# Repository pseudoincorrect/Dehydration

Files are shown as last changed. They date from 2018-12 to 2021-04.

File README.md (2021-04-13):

<h1 align="center">Dehydration Measurement System</h1>



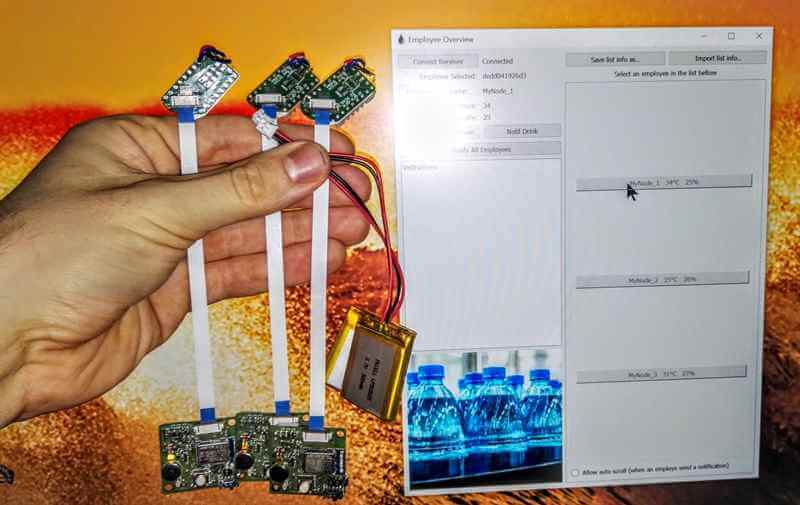
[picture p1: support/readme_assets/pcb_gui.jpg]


# Quick Description

PCB, Embedded system firmware and complementary GUI to measure the vital signs of a group of individuals.
<br>
This project's code "Dehydration" is due to the final objective to analyze data and display a dehydration level of the user. 
<br>
(Machine Learning involved, from the data science department) 
<br>

# Details

This system enable us to measure different various physical values of a group of subjects and record/display them on desktop application. The values measured are skin temperature, surrounding humidity and surrounding temperature.
<br>

## Embedded System and PCB
The embedded system communicates with bluetooth LE to a base station connected to a computer. 
<br>
It uses the Nordic NRF SDK and acts as a beacon to transmit data at regular intervals.
<br>
The PCB has been made with Eagle and assembled on premises. 
<br><br>
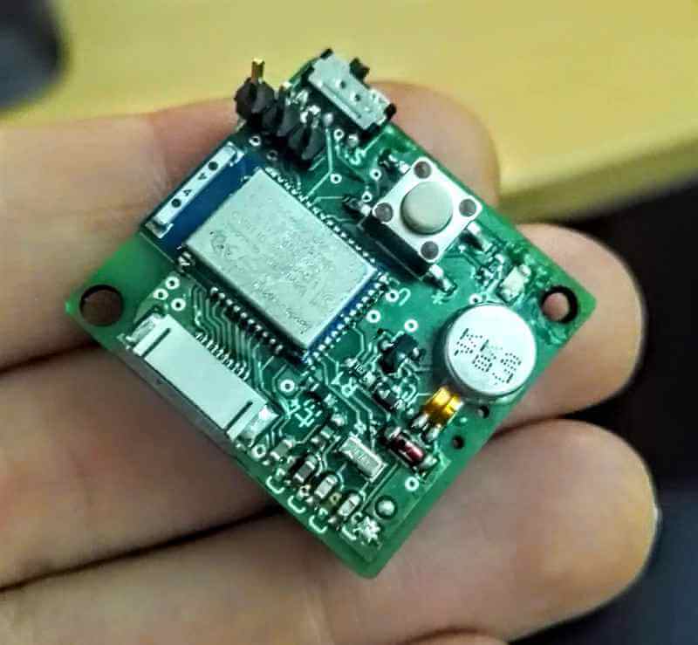
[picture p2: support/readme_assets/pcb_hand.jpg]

<br>

## GUI
The GUI is designed with Qt, PyQt more especially. 
<br>
It will search through the USB port for a base station and start receiving data when connected.
<br>
Data is then stored and displayed. The Devices are appearing and disapearing dynamically along their connections status.
<br>
Not the most elaborate UI, but it did a fine job back then and validated our proof of concept.
<br><br>

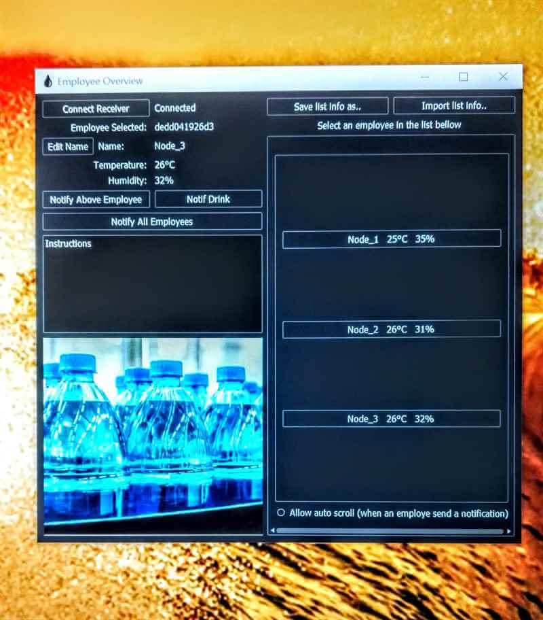
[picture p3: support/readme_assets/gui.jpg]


# Note
This project is the first version/prototype as proof of concept which lead us to continue on a following project with a higher complexity and capabilities.

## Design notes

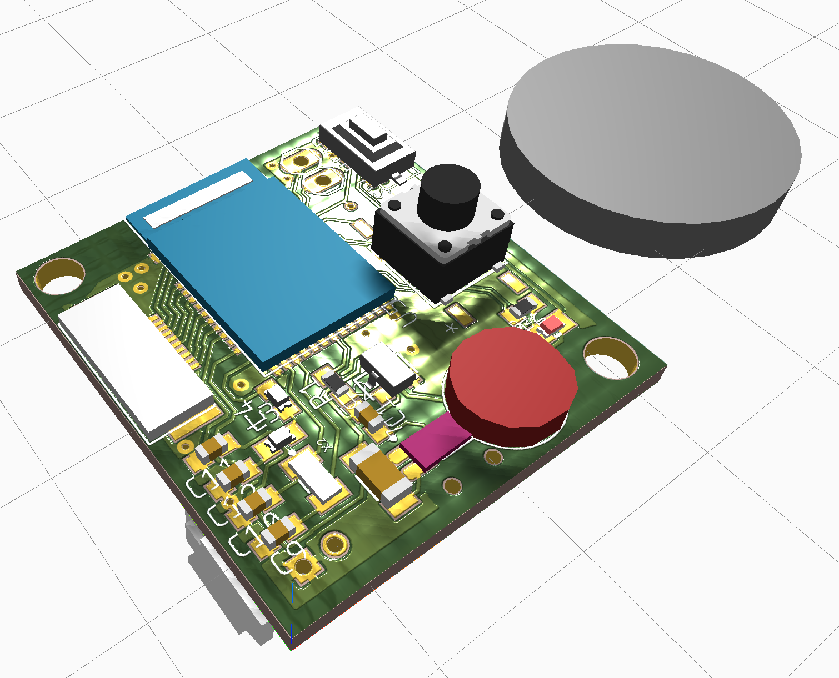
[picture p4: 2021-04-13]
dehydration_PCB/dehydration_v_0_0/picture_and_graphic/Top_view.PNG

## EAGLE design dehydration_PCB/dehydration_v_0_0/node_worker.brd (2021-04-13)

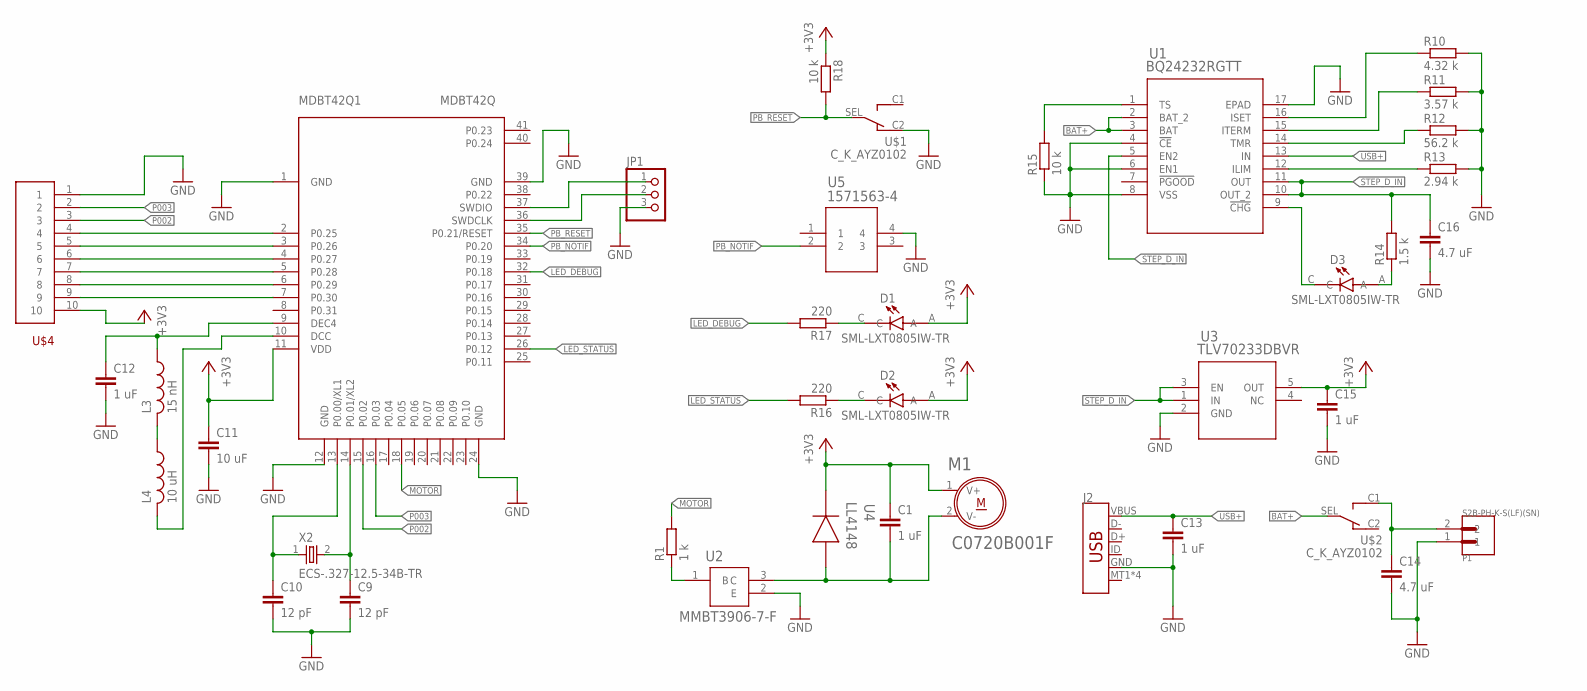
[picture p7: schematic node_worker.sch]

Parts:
C1, C12, C13, C15: 1 uF; C0603
C9, C10: 12 pF; C0603
C11: 10 uF; C0603
C14, C16: 4.7 uF; C0603
D1, D2, D3: SML-LXT0805IW-TR; LEDC2012X120N
J2: USB_MICRO-B_SMT; USB-MICROB
JP1: PINHD-1X3; 1X03
L3: 15 nH; L0603
L4: 10 uH; L0603
M1: C0720B001F; XDCR_C0720B001F
MDBT42Q1: MDBT42Q
P1: S2B-PH-K-S(LF)(SN); JST_S2B-PH-K-S(LF)(SN)
R1: 1 k; R0603
R10: 4.32 k; R0603
R11: 3.57 k; R0603
R12: 56.2 k; R0603
R13: 2.94 k; R0603
R14: 1.5 k; R0603
R15, R18: 10 k; R0603
R16, R17: 220; R0603
U1: BQ24232RGTT; RGT16_1P7X1P7
U2: MMBT3906-7-F; SOT-23
U3: TLV70233DBVR; DBV5
U4: LL4148; SOD-80
U5: 1571563-4; SWITCH_1571563-4
U$1, U$2: C_K_AYZ0102
U$4: MOLEX_FPC_10
X2: ECS-.327-12.5-34B-TR; XTAL_ECS-.327-12.5-34B-C-TR

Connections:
+3V3: C1.1, C11.1, C15.1, D1.A, D2.A, M1.1 (V+), MDBT42Q1.11 (VDD), R18.1, U3.5 (OUT), U4.CATH, U$4.10
BAT+: U1.2 (BAT_2), U1.3 (BAT), U$2.SEL
GND: C9.2, C10.2, C11.2, C12.2, C13.2, C14.2, C15.2, C16.2, J2.GND, JP1.3, MDBT42Q1.1 (GND), MDBT42Q1.12 (GND), MDBT42Q1.24 (GND), MDBT42Q1.39 (GND), P1.1, R10.2, R11.2, R12.2, R13.2, R15.1, U1.4 (!CE), U1.6 (EN1), U1.8 (VSS), U1.17 (EPAD), U2.2 (E), U3.2 (GND), U5.4, U$1.C2, U$4.1
LED_DEBUG: MDBT42Q1.32 (P0.18), R17.2
LED_STATUS: MDBT42Q1.26 (P0.12), R16.2
MOTOR: MDBT42Q1.18 (P0.05), R1.2
unnamed: C9.1, MDBT42Q1.14 (P0.01/XL2), X2.2
unnamed: L4.2, MDBT42Q1.10 (DCC)
unnamed: L3.2, L4.1
unnamed: R11.1, U1.15 (ITERM)
unnamed: C10.1, MDBT42Q1.13 (P0.00/XL1), X2.1
unnamed: JP1.2, MDBT42Q1.36 (SWDCLK)
unnamed: JP1.1, MDBT42Q1.37 (SWDIO)
unnamed: MDBT42Q1.7 (P0.30), U$4.9
unnamed: MDBT42Q1.6 (P0.29), U$4.8
unnamed: MDBT42Q1.5 (P0.28), U$4.7
unnamed: D1.C, R17.1
unnamed: D3.C, U1.9 (!CHG)
unnamed: R13.1, U1.12 (ILIM)
unnamed: C12.1, L3.1, MDBT42Q1.9 (DEC4)
unnamed: D3.A, R14.1
unnamed: R12.1, U1.14 (TMR)
unnamed: D2.C, R16.1
unnamed: R10.1, U1.16 (ISET)
unnamed: R15.2, U1.1 (TS)
unnamed: C14.1, P1.2, U$2.C1
unnamed: R1.1, U2.1 (B)
unnamed: MDBT42Q1.4 (P0.27), U$4.6
unnamed: C1.2, M1.2 (V-), U2.3 (C), U4.ANO
unnamed: MDBT42Q1.3 (P0.26), U$4.5
unnamed: MDBT42Q1.2 (P0.25), U$4.4
P002: MDBT42Q1.15 (P0.02), U$4.3
P003: MDBT42Q1.16 (P0.03), U$4.2
PB_NOTIF: MDBT42Q1.34 (P0.20), U5.2
PB_RESET: MDBT42Q1.35 (P0.21/RESET), R18.2, U$1.SEL
STEP_D_IN: C16.1, R14.2, U1.5 (EN2), U1.10 (OUT_2), U1.11 (OUT), U3.1 (IN), U3.3 (EN)
USB+: C13.1, J2.VBUS, U1.13 (IN)

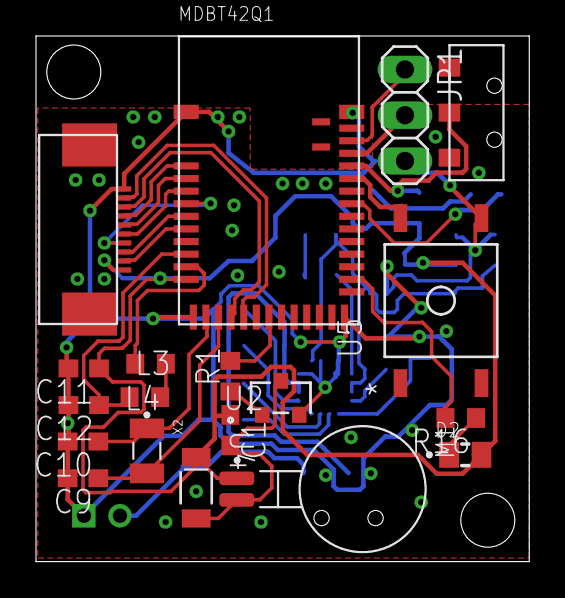
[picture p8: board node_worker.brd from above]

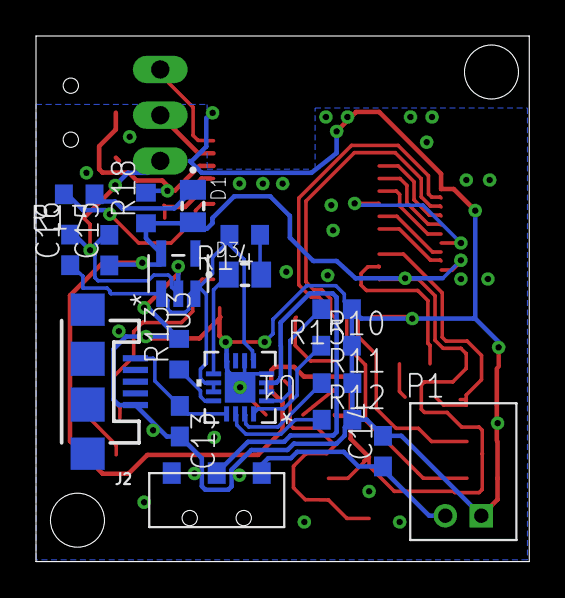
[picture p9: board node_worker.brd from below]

Board: 2 copper layers, 27.4 x 29.2 mm, 38 parts (19 on the bottom side), 37 nets.

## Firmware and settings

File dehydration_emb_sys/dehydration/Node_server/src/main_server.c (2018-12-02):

/*888888888  .d88888b.  8888888b.   .d88888b.
    888     d88P" "Y88b 888  "Y88b d88P" "Y88b
    888     888     888 888    888 888     888
    888     888     888 888    888 888     888     d8b
    888     888     888 888    888 888     888     Y8P
    888     888     888 888    888 888     888
    888     Y88b. .d88P 888  .d88P Y88b. .d88P     d8b
    888      "Y88888P"  8888888P"   "Y88888P"      Y*/

// on all address
// set advertising time
// notif all
//
// on this address
// status led to confirm addr/name
// send a quick update of the ADCs

#include "main_server.h"

//***************************************************************************
// Static data
//***************************************************************************
volatile uint8_t state = 1;
static dehydration_server_t m_server;
// sensors states
static int8_t state_dehydration;
static int8_t state_ambient_humidity;
static int8_t state_ambient_temperature;
static int8_t state_skin_temperature;
static int8_t state_heart_rate;
//
static int state_msg;
static advertiser_t m_advertiser;
static uint8_t m_adv_buffer[ADVERTISER_BUFFER_SIZE];
static ble_gap_addr_t node_addr_p;
static int FLAG_sending_notif;
static dht22_data data_dht;


/*8b     d888        d8888 8888888 888b    888
8888b   d8888       d88888   888   8888b   888
88888b.d88888      d88P888   888   88888b  888
888Y88888P888     d88P 888   888   888Y88b 888
888 Y888P 888    d88P  888   888   888 Y88b888
888  Y8P  888   d88P   888   888   888  Y88888
888   "   888  d8888888888   888   888   Y8888
888       888 d88P     888 8888888 888    Y8*/

int main(void)
{
    temperature_buffer temp_buffer;
    temp_buffer.index_buffer = 0;

    state_msg          = 0;
    FLAG_sending_notif = 0;

    nodeHal_init(OUTS_MASK, OUTPUT_DIR);
    nodeHal_write(LED_DEBUG, LED_OFF);

    nodeHal_init(PIN_TEMP_VDD_MASK, OUTPUT_DIR);
    nodeHal_write(PIN_TEMP_VDD, STD_ON);

    // SENSOR
    nodeHal_init( PIN_DHT_VDD_MASK , OUTPUT_DIR);
    nodeHal_write(PIN_DHT_VDD, STD_ON);
    DHT22_Init();

    nodeHal_buttons_init(button_event_handler);

    __LOG_INIT(LOG_SRC_APP, LOG_LEVEL_INFO, log_callback_rtt);

    __LOG(LOG_SRC_APP, LOG_LEVEL_INFO, "----- Bluetooth Mesh Beacon -----\n");

    static const uint8_t static_auth_data[NRF_MESH_KEY_SIZE] = STATIC_AUTH_DATA;
    static nrf_mesh_node_config_params_t config_params       = {
    .prov_caps = NRF_MESH_PROV_OOB_CAPS_DEFAULT(ACCESS_ELEMENT_COUNT)};

    config_params.p_static_data            = static_auth_data;
    config_params.complete_callback        = provisioning_complete;
    config_params.setup_callback           = configuration_setup;
    config_params.irq_priority             = NRF_MESH_IRQ_PRIORITY_LOWEST;
    config_params.lf_clk_cfg.source        = NRF_CLOCK_LF_SRC_SYNTH;
    config_params.lf_clk_cfg.xtal_accuracy = NRF_CLOCK_LF_XTAL_ACCURACY_250_PPM;
    //    config_params.lf_clk_cfg.source        = NRF_CLOCK_LF_SRC_XTAL;
    //    config_params.lf_clk_cfg.xtal_accuracy = NRF_CLOCK_LF_XTAL_ACCURACY_20_PPM;

    ERROR_CHECK(nrf_mesh_node_config(&config_params));

    // Start listening for incoming packets
    nrf_mesh_rx_cb_set(rx_callback);

    // Start Advertising own beacon
    init_advertiser();

    // set the addr variable used to know if a message if for us
    set_addr();

    uint8_t* msg_str = "Here we are!";

    // advertiser_enable(&m_advertiser);
    start_advertiser(msg_str);

    __LOG(LOG_SRC_APP, LOG_LEVEL_INFO, "Initialization complete!\n");

    // nodeHal_saadc_init(saadc_callback);
    nodeHal_saadc_init_simple();

    while (true) {
        (void)sd_app_evt_wait();

        get_ambient_temp_humid();
        get_temperature_mean(&temp_buffer);
        get_heart_rate();

        SEGGER_PRINTF("Ambient Temp  = %d \n\r", state_ambient_temperature);
        SEGGER_PRINTF("Ambient Humid = %d \n\r", state_ambient_humidity);
        SEGGER_PRINTF("Skin Temp     = %d \n\r", state_skin_temperature);
        SEGGER_PRINTF("Heart Rate    = %d \n\n\r", state_heart_rate);

        if (!FLAG_sending_notif) {
            change_ADC_data_advertiser();
        }
        nrf_delay_ms(1000);
    }
}

/*8b     d888 8888888888  .d8888b.  888    888     8888888b.  Y88b   d88P
8888b   d8888 888        d88P  Y88b 888    888     888   Y88b  Y88b d88P
88888b.d88888 888        Y88b.      888    888     888    888   Y88o88P
888Y88888P888 8888888     "Y888b.   8888888888     888   d88P    Y888P
888 Y888P 888 888            "Y88b. 888    888     8888888P"     d888b
888  Y8P  888 888              "888 888    888     888 T88b     d88888b
888   "   888 888        Y88b  d88P 888    888     888  T88b   d88P Y88b
888       888 8888888888  "Y8888P"  888    888     888   T88b d88P   Y8*/

static void rx_callback(const nrf_mesh_adv_packet_rx_data_t* p_rx_data) {
  int i        = 0;
  static int j = 0;
  char msg_addr[128];
  char msg[128];

  memset(msg_addr, 0, sizeof(msg_addr));
  (void)sprintf(msg_addr,
      "[%02x:%02x:%02x:%02x:%02x:%02x]",
      p_rx_data->p_metadata->params.scanner.adv_addr.addr[0],
      p_rx_data->p_metadata->params.scanner.adv_addr.addr[1],
      p_rx_data->p_metadata->params.scanner.adv_addr.addr[2],
      p_rx_data->p_metadata->params.scanner.adv_addr.addr[3],
      p_rx_data->p_metadata->params.scanner.adv_addr.addr[4],
      p_rx_data->p_metadata->params.scanner.adv_addr.addr[5]);

  memset(msg, 0, sizeof(msg));
  memcpy(msg, (uint8_t*)p_rx_data->p_payload, (uint8_t)p_rx_data->length);

  process_msg(&msg[2], p_rx_data->length - 1);
}

static void process_msg(uint8_t* msg_ptr, int msg_len) {
  char cmd_single;

  if (msg_ptr[0] == TO_ALL) {
    if (msg_ptr[1] == NOTIF_ALL) {
      SEGGER_PRINTF("%s", "process_notif_all()\n\r");
      process_notif_all();
    }
  } else if (msg_ptr[0] == TO_SINGLE) {
    if (compare_addr(&msg_ptr[1], BLE_GAP_ADDR_LEN)) {
      cmd_single = msg_ptr[CMD_CHAR_POS];
      if (cmd_single == NOTIF) {
        SEGGER_PRINTF("%s", "process_notif()\n\r");
        process_notif();
      } else if (cmd_single == DRINK_NOTIF) {
        SEGGER_PRINTF("%s", "process_notif_drink()\n\r");
        process_notif_drink();
      } else {
        SEGGER_PRINTF("Unknown command %c\n\r", msg_ptr[BLE_GAP_ADDR_LEN + 1]);
      }
    }
    // else not my address
  }
}

static void print_my_addr(uint8_t* msg_ptr) {
  int i;

  SEGGER_PRINTF("received addr : %02x%02x%02x%02x%02x%02x\n\r",
      *(msg_ptr + 1),
      *(msg_ptr + 2),
      *(msg_ptr + 3),
      *(msg_ptr + 4),
      *(msg_ptr + 5),
      *(msg_ptr + 6));

  SEGGER_PRINTF("My addr :       %s", "");

  for (i = 0; i < BLE_GAP_ADDR_LEN; i++) {
    SEGGER_PRINTF("%02x", node_addr_p.addr[i]);
  }
  SEGGER_PRINTF("\n\r%s", "");
}

static int compare_addr(uint8_t* addr_ptr, int addr_len) {
  int i;

  for (i = 0; i < BLE_GAP_ADDR_LEN; i++) {
    if (addr_ptr[i] != (node_addr_p.addr)[i]) {
      return 0;
    }
  }
  return 1;
}

static void set_addr(void) {
  advertiser_address_default_get(&node_addr_p);
}

/*8888b.   8888888888 88888888888            d8888 8888888b.  888     888
d88P  Y88b 888            888               d88888 888  "Y88b 888     888
Y88b.      888            888              d88P888 888    888 888     888
"Y888b.    8888888        888             d88P 888 888    888 Y88b   d88P
   "Y88b.  888            888            d88P  888 888    888  Y88b d88P
     "888  888            888           d88P   888 888    888   Y88o88P
Y88b  d88P 888            888          d8888888888 888  .d88P    Y888P
"Y8888P"   8888888888     888         d88P     888 8888888P"      Y*/

static void mesh_send_notif(void) {
  static char adv_msg_notif[2];
  FLAG_sending_notif = 1;

  advertiser_interval_set(&m_advertiser, ADVERTISER_PERIOD_FAST);

  adv_msg_notif[0] = NOTIF_CMD;
  adv_msg_notif[1] = 1;    // to be implemented

  set_advertiser(adv_msg_notif, sizeof(adv_msg_notif), ADVERTISER_REPEAT_ONCE);

  FLAG_sending_notif = 0;
}

static void change_ADC_data_advertiser(void) {
  int t_h_diff;
  static char adv_msg_update[7];
  adv_msg_update[0] = UPDATE_CMD;
  adv_msg_update[1] = (int8_t)(state_dehydration);
  adv_msg_update[2] = (int8_t)(state_ambient_humidity);
  adv_msg_update[3] = (int8_t)(state_ambient_temperature);
  adv_msg_update[4] = (int8_t)(state_skin_temperature);
  adv_msg_update[5] = (int8_t)(state_heart_rate);
  adv_msg_update[6] = 0;

  advertiser_interval_set(&m_advertiser, ADVERTISER_PERIOD_FAST);

  set_advertiser(adv_msg_update, sizeof(adv_msg_update), ADVERTISER_REPEAT_ONCE);
}

static void set_advertiser(char* msg_str, int len_msg, int repeat) {
  static uint8_t adv_data[128];

  memset(adv_data, 0, sizeof(adv_data));
  adv_data[0] = len_msg + 1;
  adv_data[1] = 0x2A;
  memcpy(&adv_data[2], msg_str, len_msg);

  /* Allocate packet */
  adv_packet_t* p_packet = advertiser_packet_alloc(&m_advertiser, len_msg + 2);

  if (p_packet) {
    /* Construct packet contents */
    memcpy(p_packet->packet.payload, adv_data, len_msg + 2);

    /* Repeat forever */
    p_packet->config.repeats = repeat;

    advertiser_packet_send(&m_advertiser, p_packet);
  }
}

static void init_advertiser(void) {
  advertiser_instance_dehydration_init(
      &m_advertiser, NULL, m_adv_buffer, ADVERTISER_BUFFER_SIZE, ADVERTISER_PERIOD_SLOW);
}

static void start_advertiser(uint8_t* msg_str) {
  advertiser_enable(&m_advertiser);

  static uint8_t adv_data[128];

  memset(adv_data, 0, sizeof(adv_data));
  adv_data[0] = ((uint8_t)strlen(msg_str) + 1);
  adv_data[1] = 0x2A;
  strncpy(&adv_data[2], msg_str, strlen(msg_str));

  /* Allocate packet */
  adv_packet_t* p_packet = advertiser_packet_alloc(&m_advertiser, strlen(msg_str) + 2);
  if (p_packet) {
    /* Construct packet contents */
    memcpy(p_packet->packet.payload, adv_data, strlen(msg_str) + 2);
    /* Repeat forever */
    p_packet->config.repeats = ADVERTISER_REPEAT_INFINITE;
    advertiser_packet_send(&m_advertiser, p_packet);
  }
}

static void configuration_setup(void* p_unused) {
  __LOG(LOG_SRC_APP, LOG_LEVEL_INFO, "Initializing and adding models\n");
  // Add model initialization here, if you wish to support
  // a mesh model on this node.
  nodeHal_blink(LED_STATUS, 200, 4);
}

static void provisioning_complete(void* p_unused) {
  __LOG(LOG_SRC_APP, LOG_LEVEL_INFO, "Successfully provisioned\n");
  nodeHal_blink(LED_STATUS, 200, 4);
}

/*8888b.          d8888        d8888 8888888b.   .d8888b.
d88P  Y88b       d88888       d88888 888  "Y88b d88P  Y88b
Y88b.           d88P888      d88P888 888    888 888    888
"Y888b.        d88P 888     d88P 888 888    888 888
   "Y88b.     d88P  888    d88P  888 888    888 888
     "888    d88P   888   d88P   888 888    888 888    888
Y88b  d88P  d8888888888  d8888888888 888  .d88P Y88b  d88P
"Y8888P"   d88P     888 d88P     888 8888888P"   "Y8888*/

// void saadc_callback(nrf_drv_saadc_evt_t const* p_event) {
//   if (p_event->type == NRF_DRV_SAADC_EVT_DONE) {
//     ret_code_t err_code;

//     err_code = nrf_drv_saadc_buffer_convert(p_event->data.done.p_buffer, SAMPLES_IN_BUFFER);
//     ERROR_CHECK(err_code);
//     SEGGER_PRINTF("SAADC = %d \n\r", p_event->data.done.p_buffer[0]);
//   }
//   if (!FLAG_sending_notif) {
//     change_ADC_data_advertiser();
//   }
// }

void get_temperature_mean(temperature_buffer* temp_buff)
{
    char temp_str[32];
    int16_t temp_result = 0;
    int16_t temp_mean_result = 0;
    int index = 0;
    int i = 0;

    float temperature_f;
    int   temperature_i;

    index = temp_buff->index_buffer;

    nodeHal_saadc_sample_simple(NRF_SAADC_INPUT_AIN4, (int16_t *) &temp_result);
    // nodeHal_saadc_sample_simple(SAADC_CH_PSELP_PSELP_VDD, (int16_t *) &temp_result);

    temp_buff->buffer[index] = temp_result;
    index = (index >= TEMP_BUFFER_SIZE) ? 0 : index + 1;

    temp_buff->index_buffer = index;

    for (i=0; i < TEMP_BUFFER_SIZE; i++){
        temp_mean_result += temp_buff->buffer[i];
    }
    temp_mean_result = temp_mean_result / TEMP_BUFFER_SIZE;

    temperature_f = (((float) temp_mean_result /4563) - 0.500)*100;
    temperature_i = (int) temperature_f;

    state_skin_temperature = 0x00FF & temperature_i;

    // sprintf(temp_str, "%f", temperature_f);
    // SEGGER_PRINTF("temperature_f = %s \n\r", temp_str);
    // SEGGER_PRINTF("temperature_i = %d \n\r", temperature_i);
}

void get_heart_rate(void)
{
    int16_t heart_buff;
    nodeHal_saadc_sample_simple(NRF_SAADC_INPUT_AIN5, (int16_t *) &heart_buff);
    state_heart_rate = 0x00FF & (heart_buff / 120);
}

void get_ambient_temp_humid(void)
{
    char humidity[32];
    char temperature[32];
    bool err_dht;
    ret_code_t err_code;

    err_dht = DHT22_Read (&data_dht);
    if (!err_dht) {
        SEGGER_PRINTF("DHT status = %d \n\r", err_dht);
    }
    else {
        sprintf(temperature, "%f", data_dht.temperature);
        sprintf(humidity,    "%f", data_dht.humidity);
        state_dehydration = 0;
        state_ambient_humidity    = 0x000000FF & (int) data_dht.humidity;
        state_ambient_temperature = 0x000000FF & (int) data_dht.temperature;
    }
}


/*8888b.           888    888        d8888 888b    888 8888888b.
888  "88b          888    888       d88888 8888b   888 888  "Y88b
888  .88P          888    888      d88P888 88888b  888 888    888
8888888K.          8888888888     d88P 888 888Y88b 888 888    888
888  "Y88b         888    888    d88P  888 888 Y88b888 888    888
888    888         888    888   d88P   888 888  Y88888 888    888
888   d88P         888    888  d8888888888 888   Y8888 888  .d88P
8888888P" 88888888 888    888 d88P     888 888    Y888 8888888*/

static void button_event_handler(void) {
  uint32_t nrf_status = NRF_SUCCESS;
  SEGGER_PRINTF("Button pressed %s\r\n", "");
  mesh_send_notif();
  nodeHal_blink(LED_STATUS, 50, 5);
  nodeHal_notif(MOT_NOTIF, 600, 1);
}

static void process_notif_all(void) {
  nodeHal_blink(LED_STATUS, 100, 5);
  nodeHal_notif(MOT_NOTIF, 600, 3);
}

static void process_notif(void) {
  nodeHal_blink(LED_STATUS, 100, 5);
  nodeHal_notif(MOT_NOTIF, 100, 10);
}

static void process_notif_drink(void) {
  nodeHal_blink(LED_STATUS, 100, 5);
  nodeHal_notif(MOT_NOTIF, 300, 4);
}

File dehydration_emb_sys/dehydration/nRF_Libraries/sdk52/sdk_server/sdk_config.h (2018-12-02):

/**
 * Copyright (c) 2017 - 2017, Nordic Semiconductor ASA
 * 
 * All rights reserved.
 * 
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
 * 3. Neither the name of Nordic Semiconductor ASA nor the names of its
 *    contributors may be used to endorse or promote products derived from this
 *    software without specific prior written permission.
 * 
 * 4. This software, with or without modification, must only be used with a
 *    Nordic Semiconductor ASA integrated circuit.
 * 
 * 5. Any software provided in binary form under this license must not be reverse
 *    engineered, decompiled, modified and/or disassembled.
 * 
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
 */



#ifndef SDK_CONFIG_H
#define SDK_CONFIG_H
// <<< Use Configuration Wizard in Context Menu >>>\n
#ifdef USE_APP_CONFIG
#include "app_config.h"
#endif
// <h> nRF_Drivers 

// <q> PPI_ENABLED  - nrf_drv_ppi - PPI peripheral drive
#ifndef PPI_ENABLED
#define PPI_ENABLED 1
#endif

// <e> SAADC_ENABLED - nrf_drv_saadc - SAADC peripheral driver
//==========================================================
#ifndef SAADC_ENABLED
#define SAADC_ENABLED 1
#endif
// <o> SAADC_CONFIG_RESOLUTION  - Resolution
 
// <0=> 8 bit 
// <1=> 10 bit 
// <2=> 12 bit 
// <3=> 14 bit 

#ifndef SAADC_CONFIG_RESOLUTION
#define SAADC_CONFIG_RESOLUTION 1
#endif

// <o> SAADC_CONFIG_OVERSAMPLE  - Sample period
 
// <0=> Disabled 
// <1=> 2x 
// <2=> 4x 
// <3=> 8x 
// <4=> 16x 
// <5=> 32x 
// <6=> 64x 
// <7=> 128x 
// <8=> 256x 

#ifndef SAADC_CONFIG_OVERSAMPLE
#define SAADC_CONFIG_OVERSAMPLE 0
#endif

// <q> SAADC_CONFIG_LP_MODE  - Enabling low power mode
 

#ifndef SAADC_CONFIG_LP_MODE
#define SAADC_CONFIG_LP_MODE 0
#endif

// <o> SAADC_CONFIG_IRQ_PRIORITY  - Interrupt priority
 

// <i> Priorities 0,2 (nRF51) and 0,1,4,5 (nRF52) are reserved for SoftDevice
// <0=> 0 (highest) 
// <1=> 1 
// <2=> 2 
// <3=> 3 
// <4=> 4 
// <5=> 5 
// <6=> 6 
// <7=> 7 

#ifndef SAADC_CONFIG_IRQ_PRIORITY
#define SAADC_CONFIG_IRQ_PRIORITY 7
#endif

// </e>

// <e> TIMER_ENABLED - nrf_drv_timer - TIMER periperal driver
//==========================================================
#ifndef TIMER_ENABLED
#define TIMER_ENABLED 1
#endif
// <o> TIMER_DEFAULT_CONFIG_FREQUENCY  - Timer frequency if in Timer mode
 
// <0=> 16 MHz 
// <1=> 8 MHz 
// <2=> 4 MHz 
// <3=> 2 MHz 
// <4=> 1 MHz 
// <5=> 500 kHz 
// <6=> 250 kHz 
// <7=> 125 kHz 
// <8=> 62.5 kHz 
// <9=> 31.25 kHz 

#ifndef TIMER_DEFAULT_CONFIG_FREQUENCY
#define TIMER_DEFAULT_CONFIG_FREQUENCY 0
#endif

// <o> TIMER_DEFAULT_CONFIG_MODE  - Timer mode or operation
 
// <0=> Timer 
// <1=> Counter 

#ifndef TIMER_DEFAULT_CONFIG_MODE
#define TIMER_DEFAULT_CONFIG_MODE 0
#endif

// <o> TIMER_DEFAULT_CONFIG_BIT_WIDTH  - Timer counter bit width
 
// <0=> 16 bit 
// <1=> 8 bit 
// <2=> 24 bit 
// <3=> 32 bit 

#ifndef TIMER_DEFAULT_CONFIG_BIT_WIDTH
#define TIMER_DEFAULT_CONFIG_BIT_WIDTH 0
#endif

// <o> TIMER_DEFAULT_CONFIG_IRQ_PRIORITY  - Interrupt priority
 

// <i> Priorities 0,2 (nRF51) and 0,1,4,5 (nRF52) are reserved for SoftDevice
// <0=> 0 (highest) 
// <1=> 1 
// <2=> 2 
// <3=> 3 
// <4=> 4 
// <5=> 5 
// <6=> 6 
// <7=> 7 

#ifndef TIMER_DEFAULT_CONFIG_IRQ_PRIORITY
#define TIMER_DEFAULT_CONFIG_IRQ_PRIORITY 7
#endif

// <q> TIMER0_ENABLED  - Enable TIMER0 instance
 

#ifndef TIMER0_ENABLED
#define TIMER0_ENABLED 1
#endif

// <q> TIMER1_ENABLED  - Enable TIMER1 instance
 

#ifndef TIMER1_ENABLED
#define TIMER1_ENABLED 0
#endif

// <q> TIMER2_ENABLED  - Enable TIMER2 instance
 

#ifndef TIMER2_ENABLED
#define TIMER2_ENABLED 1
#endif

// <q> TIMER3_ENABLED  - Enable TIMER3 instance
 

#ifndef TIMER3_ENABLED
#define TIMER3_ENABLED 0
#endif

// <q> TIMER4_ENABLED  - Enable TIMER4 instance
 

#ifndef TIMER4_ENABLED
#define TIMER4_ENABLED 0
#endif

// </e>

// <e> UART_ENABLED - nrf_drv_uart - UART/UARTE peripheral driver
//==========================================================
#ifndef UART_ENABLED
#define UART_ENABLED 1
#endif
// <o> UART_DEFAULT_CONFIG_HWFC  - Hardware Flow Control
 
// <0=> Disabled 
// <1=> Enabled 

#ifndef UART_DEFAULT_CONFIG_HWFC
#define UART_DEFAULT_CONFIG_HWFC 0
#endif

// <o> UART_DEFAULT_CONFIG_PARITY  - Parity
 
// <0=> Excluded 
// <14=> Included 

#ifndef UART_DEFAULT_CONFIG_PARITY
#define UART_DEFAULT_CONFIG_PARITY 0
#endif

// <o> UART_DEFAULT_CONFIG_BAUDRATE  - Default Baudrate
 
// <323584=> 1200 baud 
// <643072=> 2400 baud 
// <1290240=> 4800 baud 
// <2576384=> 9600 baud 
// <3862528=> 14400 baud 
// <5152768=> 19200 baud 
// <7716864=> 28800 baud 
// <10289152=> 38400 baud 
// <15400960=> 57600 baud 
// <20615168=> 76800 baud 
// <30801920=> 115200 baud 
// <61865984=> 230400 baud 
// <67108864=> 250000 baud 
// <121634816=> 460800 baud 
// <251658240=> 921600 baud 
// <268435456=> 1000000 baud 

#ifndef UART_DEFAULT_CONFIG_BAUDRATE
#define UART_DEFAULT_CONFIG_BAUDRATE 30801920
#endif

// <o> UART_DEFAULT_CONFIG_IRQ_PRIORITY  - Interrupt priority
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

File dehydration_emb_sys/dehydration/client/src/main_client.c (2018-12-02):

/*888888888  .d88888b.  8888888b.   .d88888b.
    888     d88P" "Y88b 888  "Y88b d88P" "Y88b
    888     888     888 888    888 888     888
    888     888     888 888    888 888     888
    888     888     888 888    888 888     888
    888     888     888 888    888 888     888
    888     Y88b. .d88P 888  .d88P Y88b. .d88P
    888      "Y88888P"  8888888P"   "Y88888*/

// Scheduler for the uart and other operations
// https://devzone.nordicsemi.com/tutorials/b/software-development-kit/posts/scheduler-tutorial

// Implement a way to send a notif to the client to enter the name of the
// server node

// Prepare the uart for the GUI

#include "main_client.h"

//****************************************************************************
// Static data
//****************************************************************************
static int selected_server;
static int selected_OP;
static int set_val;
static int state_msg;
static advertiser_t m_advertiser;
static uint8_t m_adv_buffer[ADVERTISER_BUFFER_SIZE];
static gen_fifo_t rx_fifo;
static data_packet_t rx_fifo_buf[PRE_UART_TX_BUF_SIZE];
static int str_complete;
static int32_t str_target_iter;

/*8b     d888        d8888 8888888 888b    888
8888b   d8888       d88888   888   8888b   888
88888b.d88888      d88P888   888   88888b  888
888Y88888P888     d88P 888   888   888Y88b 888
888 Y888P 888    d88P  888   888   888 Y88b888
888  Y8P  888   d88P   888   888   888  Y88888
888   "   888  d8888888888   888   888   Y8888
888       888 d88P     888 8888888 888    Y8*/

int main(void) {
  static uint8_t received_str[64];
  static command_return_t wait_set;
  state_msg       = 0;
  str_target_iter = 0;
  int ret;

  ERROR_CHECK(hal_buttons_init(button_event_handler));

  __LOG_INIT(LOG_SRC_APP, LOG_LEVEL_INFO, log_callback_rtt);
  __LOG(LOG_SRC_APP, LOG_LEVEL_INFO, "----- Bluetooth Mesh Beacon -----\n");

  static const uint8_t static_auth_data[NRF_MESH_KEY_SIZE] = STATIC_AUTH_DATA;
  static nrf_mesh_node_config_params_t config_params       = {
      .prov_caps = NRF_MESH_PROV_OOB_CAPS_DEFAULT(ACCESS_ELEMENT_COUNT)};

  config_params.p_static_data            = static_auth_data;
  config_params.complete_callback        = provisioning_complete;
  config_params.setup_callback           = configuration_setup;
  config_params.irq_priority             = NRF_MESH_IRQ_PRIORITY_LOWEST;
  config_params.lf_clk_cfg.source        = NRF_CLOCK_LF_SRC_XTAL;
  config_params.lf_clk_cfg.xtal_accuracy = NRF_CLOCK_LF_XTAL_ACCURACY_20_PPM;

  ERROR_CHECK(nrf_mesh_node_config(&config_params));

  /* Start listening for incoming packets */
  nrf_mesh_rx_cb_set(rx_callback);
  /* Start Advertising own beacon */
  init_advertiser();

  uint8_t *msg_str = "Here we are!";

  start_advertiser(msg_str);

  uart_init();

  ret = gen_fifo_init(&rx_fifo, rx_fifo_buf, PRE_UART_TX_BUF_SIZE, PRE_UART_TX_ELMT_SIZE, sizeof(rx_fifo_buf));
  ERROR_CHECK(ret);

  __LOG(LOG_SRC_APP, LOG_LEVEL_INFO, "Initialization complete!\n");

  memset(received_str, 0, sizeof(received_str));
  str_complete = 0;

  while (true) {
    //__LOG(LOG_SRC_APP, LOG_LEVEL_INFO, "Waiting for a UART message\r\n");
    uart_rx_check(received_str);

    if (str_complete == 1) {
      wait_set = select_command(received_str);
      memset(received_str, 0, sizeof(received_str));
      str_complete = 0;
    }

    if (gen_fifo_length(&rx_fifo)) {
      send_data_pc();
    }
  }
}

///////////////////////////////////////////////////////////////////////////////
///////////////////////////////////////////////////////////////////////////////
///////////////////////////////////////////////////////////////////////////////
///////////////////////////////////////////////////////////////////////////////

static void rtt_input_handler(int key) {
  if (key >= '0' && key <= '3') {
    uint32_t button_number = key - '0';
    button_event_handler(button_number);
  }
}

/*8b     d888 8888888888  .d8888b.  888    888          8888888b.  Y88b   d88P
8888b   d8888 888        d88P  Y88b 888    888          888   Y88b  Y88b d88P
88888b.d88888 888        Y88b.      888    888          888    888   Y88o88P
888Y88888P888 8888888     "Y888b.   8888888888          888   d88P    Y888P
888 Y888P 888 888            "Y88b. 888    888          8888888P"     d888b
888  Y8P  888 888              "888 888    888          888 T88b     d88888b
888   "   888 888        Y88b  d88P 888    888          888  T88b   d88P Y88b
888       888 8888888888  "Y8888P"  888    888 88888888 888   T88b d88P   Y8*/

static void rx_callback(const nrf_mesh_adv_packet_rx_data_t *p_rx_data) {
  static data_packet_t data_to_fifo;
  char msg_str[128];
  char cmd_from_node;
  int i;
  int ret;

  // LEDS_OFF(BSP_LED_0_MASK | BSP_LED_1_MASK | BSP_LED_2_MASK | BSP_LED_3_MASK);

  memset(msg_str, 0, sizeof(msg_str));

  memcpy(msg_str, (uint8_t *)p_rx_data->p_metadata->params.scanner.adv_addr.addr, (uint8_t)D_ADDR_SIZE);

  memcpy(&msg_str[D_ADDR_SIZE], (uint8_t *)&((p_rx_data->p_payload)[2]), (uint8_t)((p_rx_data->length) - 2));

  // prepare data for the fifo
  for (i = 0; i < D_ADDR_SIZE; i++) {
    data_to_fifo.d_addr[i] = msg_str[i];
  }

  cmd_from_node          = msg_str[D_COMMAND_POS];
  data_to_fifo.d_command = cmd_from_node;

  if (cmd_from_node == UPDATE_CMD) {
    data_to_fifo.d_dehydration         = msg_str[D_DEHYDRATION];
    data_to_fifo.d_ambient_humidity    = msg_str[D_AMBIENT_HUMIDITY];
    data_to_fifo.d_ambient_temperature = msg_str[D_AMBIENT_TEMPERATURE];
    data_to_fifo.d_skin_temperature    = msg_str[D_SKIN_TEMPERATURE];
    data_to_fifo.d_heart_rate          = msg_str[D_HEART_RATE];
    data_to_fifo.d_dummy               = msg_str[D_DUMMY];
    // data_to_fifo.d_dehydration = ((msg_str[D_DEHYDRATION_MSB] << 8) | (msg_str[D_DEHYDRATION_LSB]));
    // data_to_fifo.d_humidity    = ((msg_str[D_HUMIDITY_MSB] << 8) | (msg_str[D_HUMIDITY_LSB]));
    // data_to_fifo.d_temperature = ((msg_str[D_TEMPERATURE_MSB] << 8) | (msg_str[D_TEMPERATURE_LSB]));
  } else if (cmd_from_node == NOTIF_CMD) {
    data_to_fifo.d_dehydration         = 0;
    data_to_fifo.d_ambient_humidity    = msg_str[D_NOTIF];
    data_to_fifo.d_ambient_temperature = 0;
    data_to_fifo.d_skin_temperature    = 0;
    data_to_fifo.d_heart_rate          = 0;
    data_to_fifo.d_dummy               = 0;
    // data_to_fifo.d_dehydration = msg_str[D_DEHYDRATION_MSB];
    // data_to_fifo.d_humidity    = 0;
    // data_to_fifo.d_temperature = 0;
  } else {
    SEGGER_PRINTF("Unknown mesh command\r\n", "");
  }

  ret = gen_fifo_write(&rx_fifo, &data_to_fifo);

  if (ret != NRF_SUCCESS) {
    SEGGER_PRINTF("%s\r\n", "write failed, flushing fifo");
    gen_fifo_flush(&rx_fifo);
  }
}
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

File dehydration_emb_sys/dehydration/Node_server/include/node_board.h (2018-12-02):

#ifndef NODE_BOARD_H
#define NODE_BOARD_H

//#include "pca10040.h"

// Low frequency clock source to be used by the SoftDevice
//#define NRF_CLOCK_LFCLKSRC      {.source       = NRF_CLOCK_LF_SRC_XTAL,      \
//                                 .rc_ctiv      = 0,                          \
//                                 .rc_temp_ctiv = 0,                          \
//                                 .accuracy     = NRF_CLOCK_LF_ACCURACY_20_PPM}


//#define NRF_CLOCK_LFCLKSRC      {.source       = NRF_CLOCK_LF_SRC_RC,      \
//                                 .rc_ctiv      = 16,                          \
//                                 .rc_temp_ctiv = 0,                          \
//                                 .accuracy     = 0}

// outputs
#define LED_STATUS 12
#define PIN_LED_STATUS LED_STATUS
#define PIN_LED_STATUS_MASK (1 << PIN_LED_STATUS)

#define LED_DEBUG 18
#define PIN_LED_DEBUG LED_DEBUG
#define PIN_LED_DEBUG_MASK (1 << PIN_LED_DEBUG)

#define MOT_NOTIF 5
#define PIN_MOT_NOTIF MOT_NOTIF
#define PIN_MOT_NOTIF_MASK (1 << PIN_MOT_NOTIF)

#define OUTS_MASK (PIN_LED_STATUS_MASK | PIN_LED_DEBUG_MASK | PIN_MOT_NOTIF_MASK )

#define BUTTON 20
#define PIN_BUTTON BUTTON
#define PIN_BUTTON_MASK (1 << PIN_BUTTON)

#define DHT_VDD 3
#define PIN_DHT_VDD DHT_VDD
#define PIN_DHT_VDD_MASK (1 << PIN_DHT_VDD)

#define DHT_DATA 2
#define PIN_DHT_DATA DHT_DATA
#define PIN_DHT_DATA_MASK (1 << PIN_DHT_DATA)

#define TEMP_VDD 27
#define PIN_TEMP_VDD TEMP_VDD
#define PIN_TEMP_VDD_MASK (1 << PIN_TEMP_VDD)

#define TEMP_SKIN 28
#define PIN_TEMP_SKIN TEMP_SKIN
#define PIN_TEMP_SKIN_MASK (1 << PIN_TEMP_SKIN)
#define TEMP_SKIN_AIN  4

#define DHT22_TIMER   NRF_TIMER3

//#define OUT_ON(out_mask) do {  ASSERT(sizeof(out_mask) == 4);                 \
//                        NRF_GPIO->OUTSET = (out_mask) & (OUTS_MASK); } while (0)
//
//#define OUT_OFF(out_mask) do {  ASSERT(sizeof(out_mask) == 4);                \
//                       NRF_GPIO->OUTCLR = (out_mask) & (OUTS_MASK);} while (0)

//#define OUT_ON(out_mask) do { nrf_gpio_pin_write(out_mask, 1);  } while (0)
//
//#define OUT_OFF(out_mask) do { nrf_gpio_pin_write(out_mask, 0); } while (0)
//
//#define OUTS_INVERT(out_mask) do { uint32_t gpio_state = NRF_GPIO->OUT;      \
//                              ASSERT(sizeof(out_mask) == 4);                 \
//                              NRF_GPIO->OUTSET = ((out_mask) & ~gpio_state); \
//                              NRF_GPIO->OUTCLR = ((out_mask) & gpio_state); } while (0)
//
//#define OUTS_CONFIGURE(out_mask) do { uint32_t pin;                  \
//                                  ASSERT(sizeof(out_mask) == 4);     \
//                                  for (pin = 0; pin < 32; pin++)      \
//                                      if ( (out_mask) & (1 << pin) ) \
//                                          nrf_gpio_cfg_output(pin); } while (0)

#endif

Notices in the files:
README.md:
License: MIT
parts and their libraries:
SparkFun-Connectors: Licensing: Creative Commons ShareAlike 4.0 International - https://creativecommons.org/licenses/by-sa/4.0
